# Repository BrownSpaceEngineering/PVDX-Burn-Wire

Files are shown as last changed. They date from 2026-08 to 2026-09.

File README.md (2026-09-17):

# BurnWire

Burn-wire release board for the PVDX CubeSat. Generates a constant current of 1.6A through a nichrome wire to sever the retention line holding deployable camera arm in its stowed position.

## Status
- Design phase: manufactured (rev-3.1 sent to fab 2026-08-22)
- Current rev: rev-3.1
- Contributors: Atharv Chowdhary, Nick Cavallo, Jayla Hsiung, Emily Zhang, Kelly Lin, Natalie Cavallo, Misha Zinchuk

## System overview

BurnWire was originally forked from another team's Altium-designed board and imported into KiCad, which is the source of most of the quirks documented below. 

**WIP**
Known components on the board (confirmed via schematic/PCB library references, not yet mapped to a full circuit description — fill in as this gets documented properly):

- **ADP2303ARDZ** — synchronous step-down switching regulator. Per standing design notes, this part needs a Schottky diode (e.g. BAT54, here likely the placed **B330B-13-F**) from V_in to the BST pin to prevent bootstrap collapse at 5V input (datasheet Figure 48) — worth confirming this placement is present and correctly oriented.
- **B330B-13-F** — Schottky diode, SMB package (3 footprint variants exist in `libs/footprints.pretty/`: base, `-M`, `-L`; the placed instance uses `-L`).
- **IND_NLV32T_TDK** (TDK NLV32T-3R3J-EF, 3.3µH) and **Bourns SRN6045** — two inductor footprints present; [confirm: both used in the regulator stage, or does one serve the burn-wire drive circuit?]
- **JST B6B-XH-A** 6-pin connector — external interface (power / command / burn-wire line — confirm pinout).
- 0.25Ω 3W power resistor (2512/2010 footprint) — likely current-sense or burn-wire load-adjacent; confirm function.
- Standard passives: 0603/0805 resistors, 0603 100nF decoupling caps, WCAP-ASLI 5x5.5mm bulk electrolytic.
- Test points inherited from the original board's library (`PowerManagmentBoard_V4.0:TP` nickname — currently orphaned, see Open Items).

### Repo layout
```
BurnWire/
├── BurnWire.kicad_pro / .kicad_sch / .kicad_pcb / .step
├── LTSpice_burnWire.asc
├── fp-lib-table, sym-lib-table
├── libs/
│   ├── footprints.pretty/
│   └── symbols/
└── manufacturing/
    └── rev-1_2026-08-22/
        └── gerbers/
```
No schematics/, spice/, or tools/ directories — the LTSpice simulation is currently stored at the repository root as LTSpice_burnWire.asc.

## Key design notes
- **Inherited from Altium, not yet fully re-linked in KiCad.** Nearly every custom part on the schematic (`Burn Wire Dev Board-altium-import:*`, `Burn Wire Dev Board:root_N_*`, `PowerManagmentBoard_V4.0:*`) has no corresponding entry in `sym-lib-table`. The schematic still opens and renders correctly because KiCad caches each symbol's full geometry inline at placement time — `sym-lib-table` is only consulted when re-editing or re-placing a symbol. Don't take "it opens fine" as evidence the library links are healthy.
- **PCB layer names are non-standard**, carried over from the Altium import (e.g. `Mechanical 1/5/7/13/15`, `User.2/3/4` instead of KiCad's standard `Margin`/`User.Comments`/etc.). Not remapped in this reorg — flagged as a full production-file redo for later, out of scope for repo hygiene.
- **ADP2303 bootstrap diode** — see System overview above; this is a known failure mode for this regulator at 5V input, worth double-checking against the datasheet if this board is ever re-spun.
- `libs/symbols/` now holds four properly filed vendor symbols (B330B-13-F, B6B-XH-A_LF__SN_, NLV32T-3R3J-EF, WCAP-ASLI_5X5.5), but **none are currently referenced by the schematic** — the placed parts use generic `Device:`/`Connector:` symbols instead. These are available for future use, not currently wired in.

## Simulations
- `LTSpice_burnWire.asc` — LTSpice simulation of the burn-wire constant-current regulator.

## Manufacturing history
| Rev | Date | Notes | Location |
|-----|---|---|---|
| 3.1 | 2026-08-22 | First fab | `manufacturing/rev-1_2026-08-22/gerbers/` |

## Open items / TBD
- PCB layer names still reflect the Altium import (`Mechanical 1/5/7/13/15`, `User.2/3/4`) — needs remapping to standard KiCad layers as part of a full production-file redo.
- `burn_wire:CR_SMB_320-345BE_DIO-L` and `burn_wire:IND_BOURNS_SRN6045` footprint nicknames on the PCB aren't yet re-linked to the `footprints` library in `fp-lib-table` — the backing files exist in `libs/footprints.pretty/` now, they just need the reference updated.
- `Burn Wire Dev Board:0603` and `PowerManagmentBoard_V4.0:TP` footprint nicknames have no backing file anywhere in the repo — genuinely missing, not just unlinked.
- Most schematic symbols are unlinked from `sym-lib-table` (see Key design notes) — re-linking or rebuilding these is a real schematic-level task, not a file move.
- The placed `burn_wire:CR_SMB_320-345BE_DIO-L` instance has a pad offset that doesn't cleanly match either library copy of that footprint (hand-nudged geometry) — worth a visual QC pass against the fabbed rev-1 board.

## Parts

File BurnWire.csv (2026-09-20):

Reference | Qty | Value | DNP | Exclude from BOM | Exclude from Board | Footprint | Datasheet
C1 | 1 | 0.1uF |  |  |  | Capacitor_THT:CP_Axial_L10.0mm_D4.5mm_P15.00mm_Horizontal | ~
C2 | 1 | 10uF |  |  |  | Capacitor_THT:CP_Axial_L10.0mm_D4.5mm_P15.00mm_Horizontal | ~
C3,C4 | 2 | WCAP-ASLI_5X5.5 |  |  |  | WCAP-ASLI:WCAP-ASLI_5X5.5_DXL_
CR1 | 1 | B330B-13-F |  |  |  | imported_footprints:CR_SMB_320-345BE_DIO | B330B-13-F
J1 | 1 | B6B-XH-A_LF__SN_ |  |  |  | imported_footprints:JST_B6B-XH-A_LF__SN_
L1 | 1 | SRN6045-3R3Y |  |  |  | IND_BOURNS_SRN6045 | SRN6045-3R3Y
R3 | 1 | 100K |  |  |  | Resistor_THT:R_Axial_DIN0204_L3.6mm_D1.6mm_P5.08mm_Horizontal | ~
RBott?,RTop? | 2 | 10k |  |  |  |  | ~
TP1,TP2 | 2 | TestPoint_Alt |  |  |  |  | ~
U1 | 1 | ADP2303ARDZ |  |  |  | Package_SO:SOIC-8-1EP_3.9x4.9mm_P1.27mm_EP2.29x3mm | https://www.analog.com/media/en/technical-documentation/data-sheets/ADP2302_2303.pdf

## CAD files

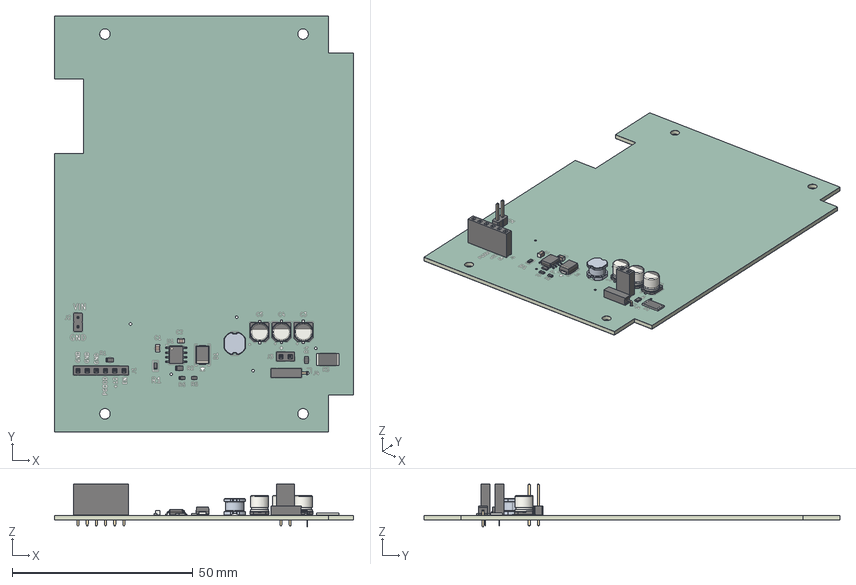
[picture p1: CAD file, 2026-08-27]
BurnWire.step
82.8 x 115.0 x 11.8 mm
CP_Elec_5x54 x 3
R_0805_2012Metric x 3
R_0603_1608Metric x 3
C_0805_2012Metric x 2
SRN6045
D_SMB
PinSocket_1x01_P2.54mm_Horizontal
PinSocket_1x06_P2.54mm_Vertical
SOIC-8-1EP_3.9x4.9mm_P1.27mm_EP2.29x3mm
PinSocket_1x02_P2.54mm_Vertical
PinHeader_1x02_P254mm_Vertical
R_2512_6332Metric
BurnWire_silkscreen
BurnWire_soldermask x 2
BurnWire_PCB

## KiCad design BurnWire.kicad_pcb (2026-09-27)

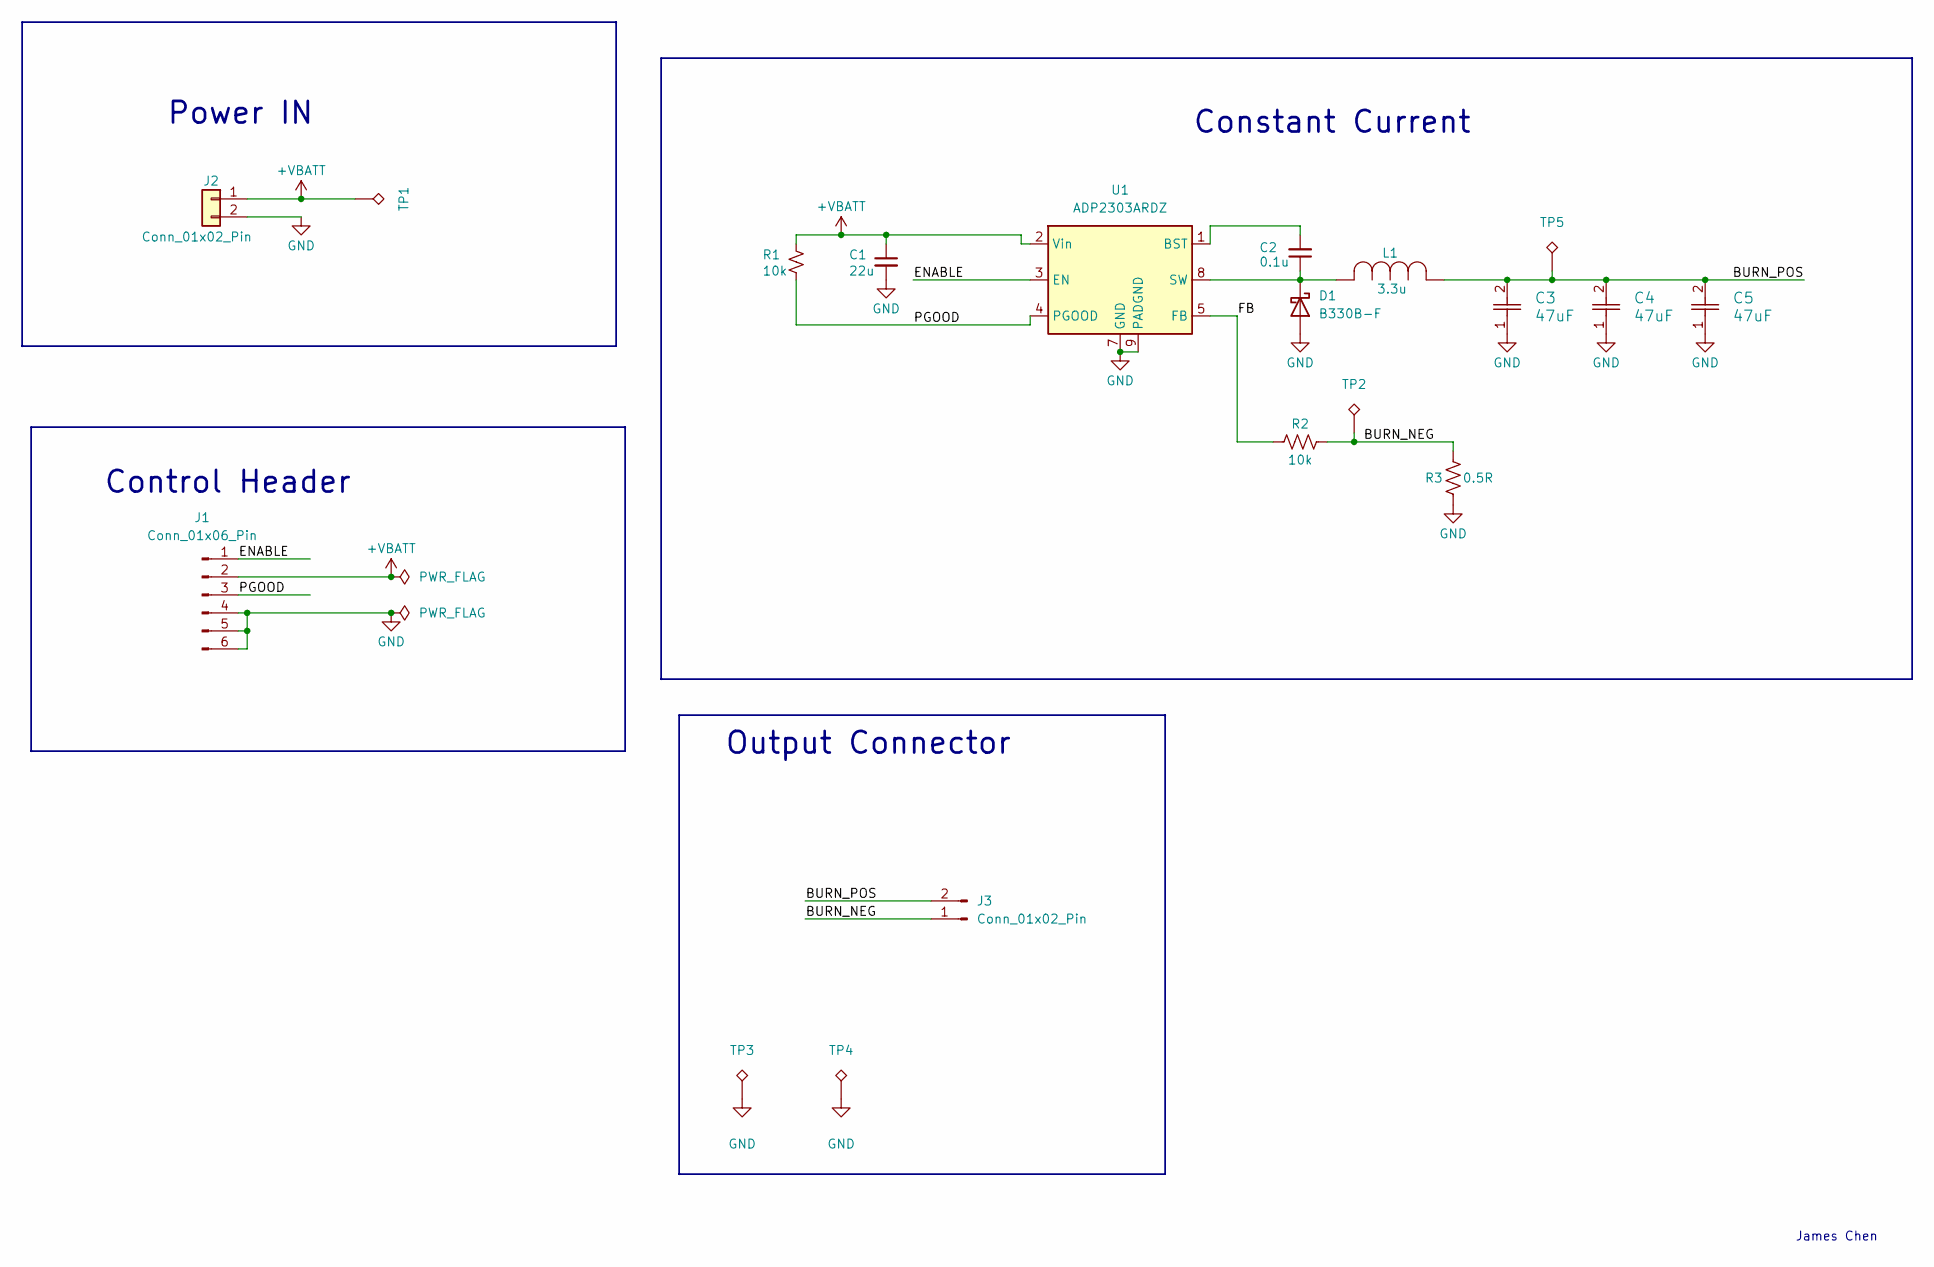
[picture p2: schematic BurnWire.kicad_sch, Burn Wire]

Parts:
C1: 22u; C_0805_2012Metric_Pad1.18x1.45mm_HandSolder; MANUFACTURER PART # TPSA226K010T0900
C2: 0.1u; C_0805_2012Metric_Pad1.18x1.45mm_HandSolder; MANUFACTURER PART # CL10B104KA8NNNC
C3, C4, C5: 47uF; CAP_GRM_32E_MUR
D1: B330B-F; CR_SMB_320-345BE_DIO-L; MANUFACTURER PART # B330B-13-F
J1: Conn_01x06_Pin; PinSocket_1x06_P2.54mm_Vertical
J2: Conn_01x02_Pin; PinHeader_1x02_P2.54mm_Vertical; MANUFACTURER PART # 282834-2
J3: Conn_01x02_Pin; PinSocket_1x02_P2.54mm_Vertical
L1: 3.3u; IND_BOURNS_SRN6045; MANUFACTURER PART # IHLP4040DZER6R8M01
R1, R2: 10k; R_0805_2012Metric_Pad1.20x1.40mm_HandSolder; MANUFACTURER PART # RNCP0603FTD10K0
R3: 0.5R; R_2512_6332Metric; MANUFACTURER PART # WSLT2010R2500FEA18
TP1, TP2, TP3, TP4, TP5: TP; TestPoint_Loop_D1.80mm_Drill1.0mm_Beaded
U1: ADP2303ARDZ; SOIC-8-1EP_3.9x4.9mm_P1.27mm_EP2.29x3mm

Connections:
+VBATT: C1.1, J1.2, J2.1, R1.2, TP1.1 (1_1), U1.2 (Vin)
/BURN_NEG: J3.1, R2.2, R3.2, TP2.1 (1_1)
/BURN_POS: C3.2, C4.2, C5.2, J3.2, L1.1, TP5.1 (1_1)
/ENABLE: J1.1, U1.3 (EN)
/FB: R2.1, U1.5 (FB)
/PGOOD: J1.3, R1.1, U1.4 (PGOOD)
GND: C1.2, C3.1, C4.1, C5.1, D1.2 (A), J1.4, J1.5, J1.6, J2.2, R3.1, TP3.1 (1_1), TP4.1 (1_1), U1.7 (GND), U1.9 (PADGND)
unnamed: C2.1, D1.1 (K), L1.2, U1.8 (SW)
unnamed: C2.2, U1.1 (BST)

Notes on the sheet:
Control Header
Output Connector
James Chen
Power IN
Constant Current

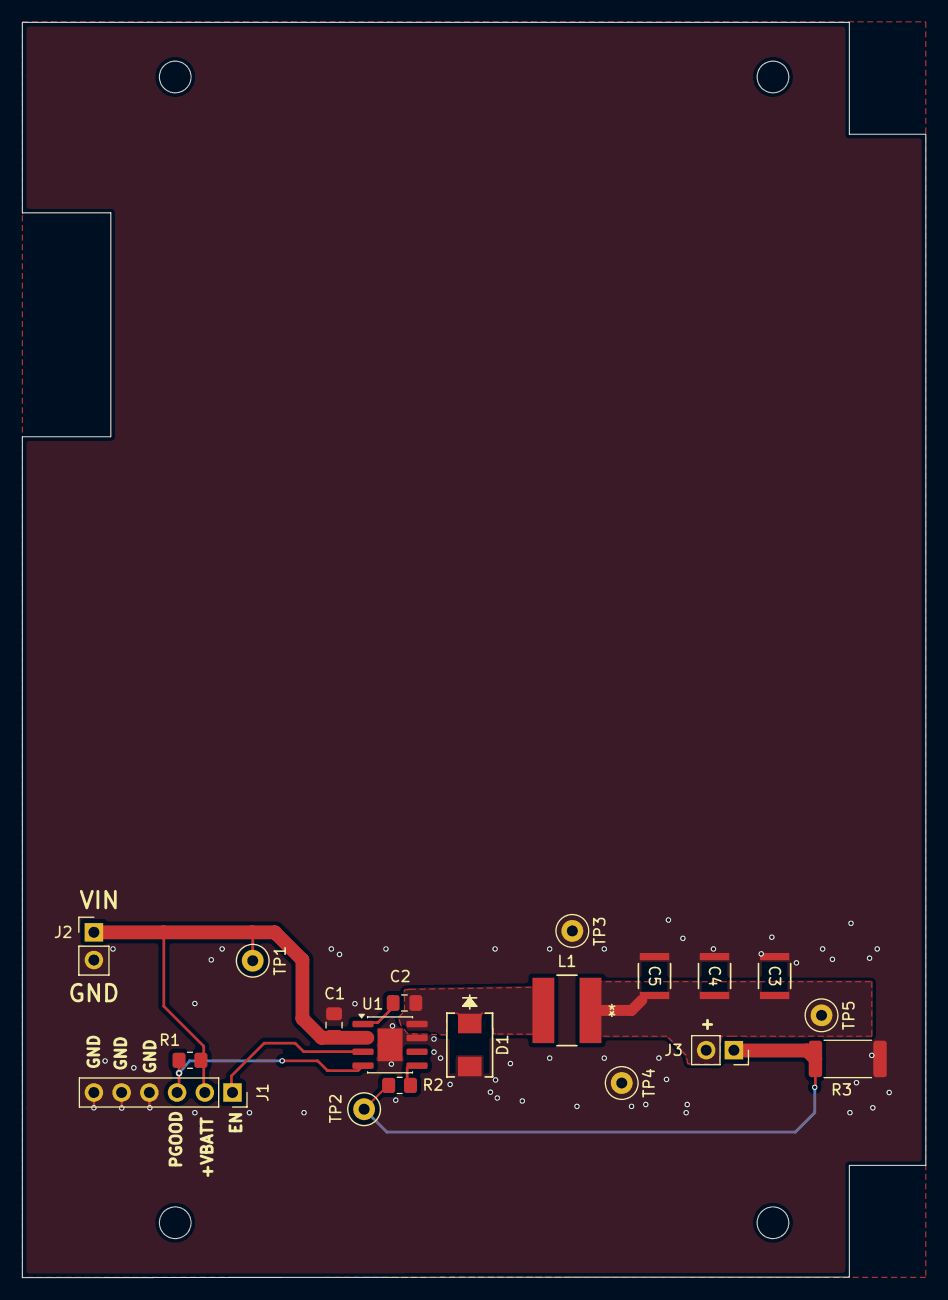
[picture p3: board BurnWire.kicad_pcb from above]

Board: 2 copper layers, 82.8 x 115.0 mm, 19 parts (0 on the bottom side), 9 nets.

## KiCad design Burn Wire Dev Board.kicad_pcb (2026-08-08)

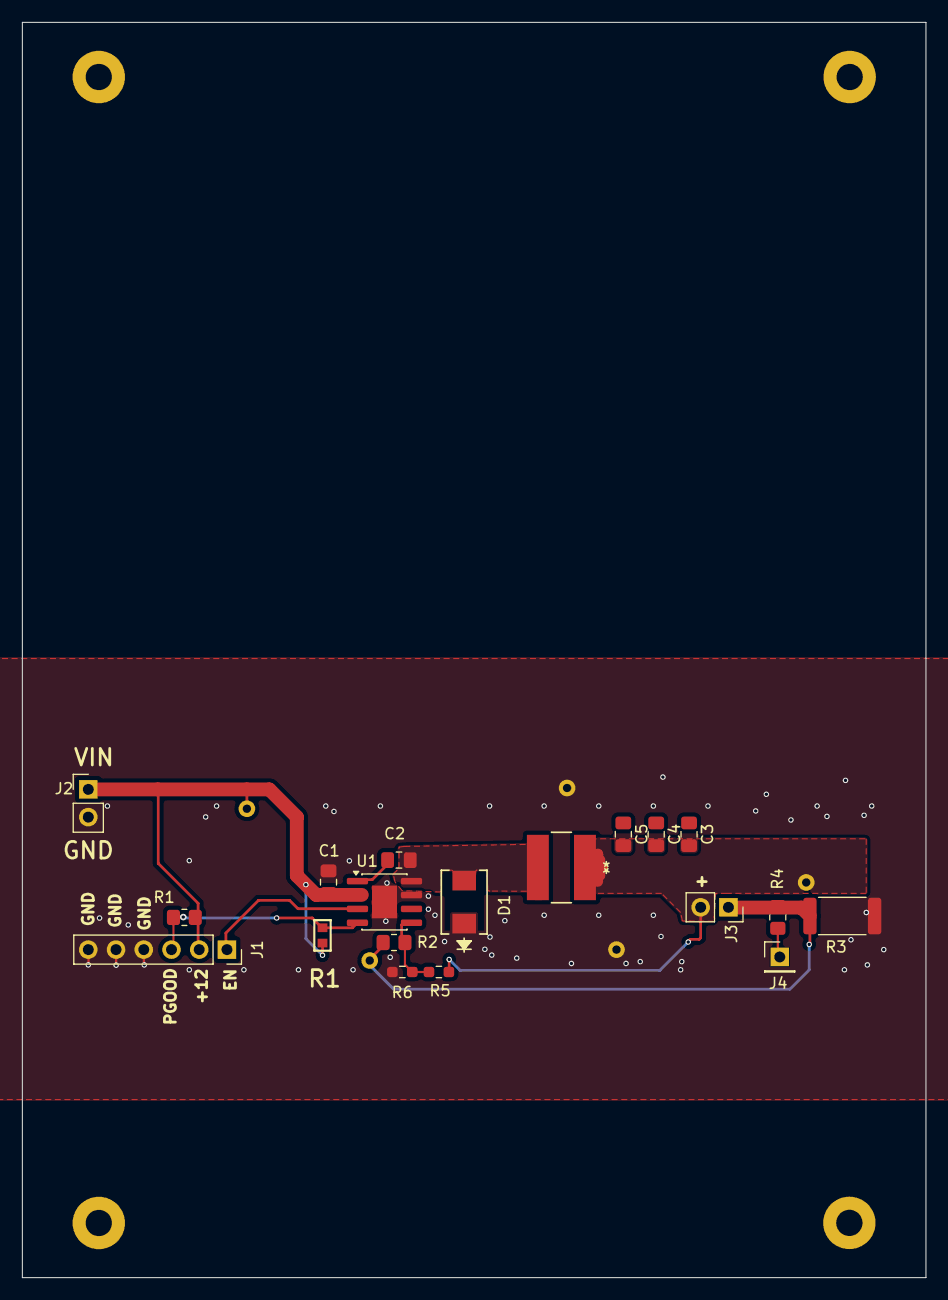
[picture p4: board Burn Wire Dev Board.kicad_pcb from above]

Board: 2 copper layers, 82.8 x 115.0 mm, 28 parts (0 on the bottom side), 10 nets.

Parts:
*1, *2, *3, *3#2: M2 Mounting; M2 Screws
C1: 22uF; C_0805_2012Metric_Pad1.18x1.45mm_HandSolder
C2: 0.1uF; C_0805_2012Metric_Pad1.18x1.45mm_HandSolder
C3, C4, C5: 47 uF; C_0805_2012Metric_Pad1.18x1.45mm_HandSolder
D1: D_Schottky; CR_SMB_320-345BE_DIO-L
J1: Conn_01x06_Pin; PinSocket_1x06_P2.54mm_Vertical
J2: 282834-2; PinHeader_1x02_P2.54mm_Vertical
J3: Conn_01x02_Pin; PinSocket_1x02_P2.54mm_Vertical
J4: Conn_01x01_Pin; PinHeader_1x01_P2.54mm_Vertical
L1: 6.8 UH; IND_BOURNS_SRN6045
R1: 10K; 0603
R1#2, R2: 10K; R_0805_2012Metric_Pad1.20x1.40mm_HandSolder
R3: 0.25R; R_2512_6332Metric
R4: 1k; R_0805_2012Metric_Pad1.20x1.40mm_HandSolder
R5, R6: 0R; R_0603_1608Metric_Pad0.98x0.95mm_HandSolder
TP1, TP2, TP3, TP4, TP5: TP
U1: ADP2303ARDZ; SOIC-8-1EP_3.9x4.9mm_P1.27mm_EP2.29x3mm

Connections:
+VBATT: C1.1, J1.2, J2.1, R1.2, R1#2.2, TP2.1, U1.2 (Vin)
/BURN_NEG: J3.1, R2.2, R3.2, R4.1, TP3.1
/BURN_POS: C3.1, C4.1, C5.1, J3.2, R5.2, TP1.1
/ENABLE: J1.1, U1.3 (EN)
GND: *1.1, C1.2, C3.2, C4.2, C5.2, D1.1 (K), J1.4, J1.5, J1.6, J2.2, R3.1, R6.1, TP4.1, TP5.1, U1.7 (GND), U1.9 (PADGND)
unnamed: C2.1, D1.2 (A), L1.2 (2_2), U1.8 (SW)
unnamed: C2.2, U1.1 (BST)
unnamed: R2.1, R5.1, R6.2, U1.5 (FB)
PGOOD: J1.3, R1.1, R1#2.1, U1.4 (PGOOD)
TO_COMPUTE: J4.1 (Pin_1_1), R4.2

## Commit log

2025-11-02 Initial commit of KiCAD files for burn wire circuit
    [BurnWire.kicad_sch]
2025-11-02 completed schematic, added most footprints
    [B6B-XH-A_LF__SN_.step, BurnWire.kicad_sch]
2025-11-02 Added footprint libraries, reorganized imported components, Assigned footprints
    [B6B-XH-A_LF__SN_.step, BurnWire.kicad_sch]
2025-11-04 imported more footprints, completed layout
    [BurnWire.kicad_pcb, BurnWire.kicad_sch, WCAP-ASLI_5X5.5.step]
2025-11-16 Add design rules to layout
    [BurnWire.kicad_pcb]
2025-11-20 reworked most of the layout
    [BurnWire.kicad_pcb]
2025-11-23 finished routing
    [BurnWire.kicad_pcb]
2025-11-26 burnwire design complete
    [BurnWire.kicad_pcb]
2026-01-30 reduced number of vias
    [BurnWire.kicad_pcb]
2026-02-06 fixed some DRC violations
    [BurnWire.kicad_pcb]
2026-02-06 unflipped version; passes DRC
    [BurnWire.kicad_pcb]
2026-02-08 done layout
    [BurnWire.kicad_pcb]
2026-02-08 optimized layout
    [BurnWire.kicad_pcb]
2026-02-08 generated gerber
    [BurnWire.kicad_pcb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]
2026-02-13 redid layout
    [BurnWire.kicad_pcb]
2026-08-07 layout for const curr
    [Burn Wire Dev Board.kicad_pcb, Burn Wire Dev Board.kicad_sch, BurnWire.kicad_pcb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]
2026-08-08 current sensor added to schematic
2026-08-08 current sensor added to schematic forgot to save
    [Burn Wire Dev Board.kicad_sch]
2026-08-08 added compute resistor tolayout
    [Burn Wire Dev Board.kicad_pcb, Burn Wire Dev Board.kicad_sch]
2026-08-08 fixed physical dim to have edgecuts
    [Burn Wire Dev Board.kicad_pcb]
2026-08-20 clean layout; reorg: rename project to BurnWire, add gitignore
    [BurnWire.kicad_pcb, BurnWire.kicad_sch]
2026-08-21 Fix unrouted areas, board dimensions
    [BurnWire.kicad_pcb, BurnWire.kicad_sch]
2026-08-22 Add gerbers
    [BurnWire.kicad_pcb]
2026-08-22 Actually add gerbers
    [BurnWire-Bottom Layer.gbr, BurnWire-Bottom Overlay.gbr, BurnWire-Bottom Paste.gbr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]
2026-08-27 generate STEP, clean repo, fix silkscreen
    [BurnWire.kicad_pcb, BurnWire.step]
2026-08-27 reorg: move gerbers
    [BurnWire-Bottom Layer.gbr, BurnWire-Bottom Overlay.gbr, BurnWire-Bottom Paste.gbr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]
2026-09-20 Removed all Altium references, fixed D1 direction, prepare for Rev 4.0
    [BurnWire.csv, BurnWire.kicad_pcb, BurnWire.kicad_sch]
2026-09-26 change resistor to 0.5R and delete redundant resistors
    [BurnWire.kicad_pcb, BurnWire.kicad_sch]
2026-09-26 switch to ceramic capacitors and fix via violations
    [BurnWire.kicad_pcb, BurnWire.kicad_sch]
2026-09-27 add text to pcb
    [BurnWire.kicad_pcb]
